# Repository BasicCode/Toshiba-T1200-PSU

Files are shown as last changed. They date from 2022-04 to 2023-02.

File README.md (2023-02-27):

# Toshiba-T1200-PSU
A replacement power supply design for the Toshiba T1200 laptop computer from 1987. The Toshiba T1xxx series are notorious for power supply falures, and the power supply design is complex for the era. While the complicated design did allow for some innovative new power management features for the time, it also allowed for a myriad of annoying failure modes. I say this only because I have not implemented most of the auxiliary features here, but they may be desirable in the future.<br />
<br />
This is revision one, it has the basic requirements to make the machine boot but it lacking any of the extra features of the original supply. **Also, please read the note about input / output protection**. I have used modular power options where possible and have tried to follow the recommended design for the -22V SMPS circuit as closely as possible. Please feel free to improve on this design.
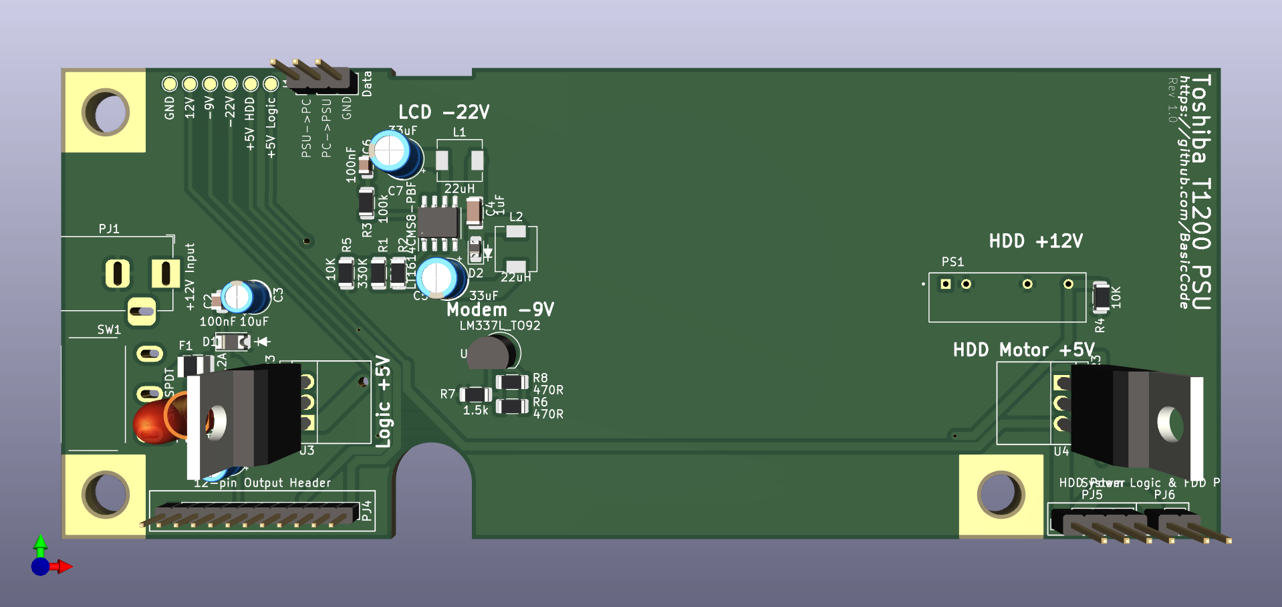
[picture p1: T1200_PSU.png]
Board Simulation


## Getting Started
This board is designed in KiCad 6.x, custom and third-party footprints are included in the repository, and the individual Gerber files are included.
* Parts list for DigiKey is available [here](https://www.digikey.com.au/en/mylists/list/S7I768EYZQ). All of the passives are generic and can be replaced with whatever you have laying around, just take care to use low ESR 33uF caps for the -22V SMPS. Two parts are missing from the list; the female headers for the interconnect between the PSU and the Motherboard. They are generic keyed headers like these: (https://www.jaycar.com.au/4-pin-0-1-header-with-crimp-pins-2-54-pitch/p/HM3404), (https://www.jaycar.com.au/2-pin-0-1-header-with-crimp-pins-2-54-pitch/p/HM3402).
* The board is designed to use 12V, like the original, however the invdividual switchmode supplies have different tollerances so you might be able to get away with other supplies but check the datasheets first.
* I used OSH Park to print the boards (https://oshpark.com/shared_projects/8MR7H5RI).
* The footprint for the DC Barrel Jack 12V input *should* fit the jack on the original PCB if you want to use that, however I have used a more standard size plug and a modern, off-the-shelf, 12V plug pack. The original power supply is rated for 2.2A.
* I measured the whole system at boot to draw approx. 700mA at 12V.
* There is NO output protection, so if you build one of these then make sure to check the voltage rails before using it.

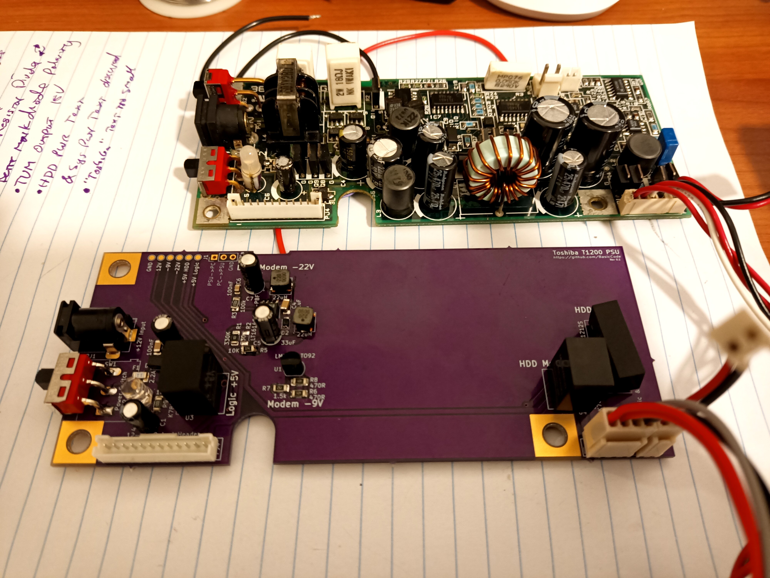
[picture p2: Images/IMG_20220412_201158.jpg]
New board and old board New Board and old board

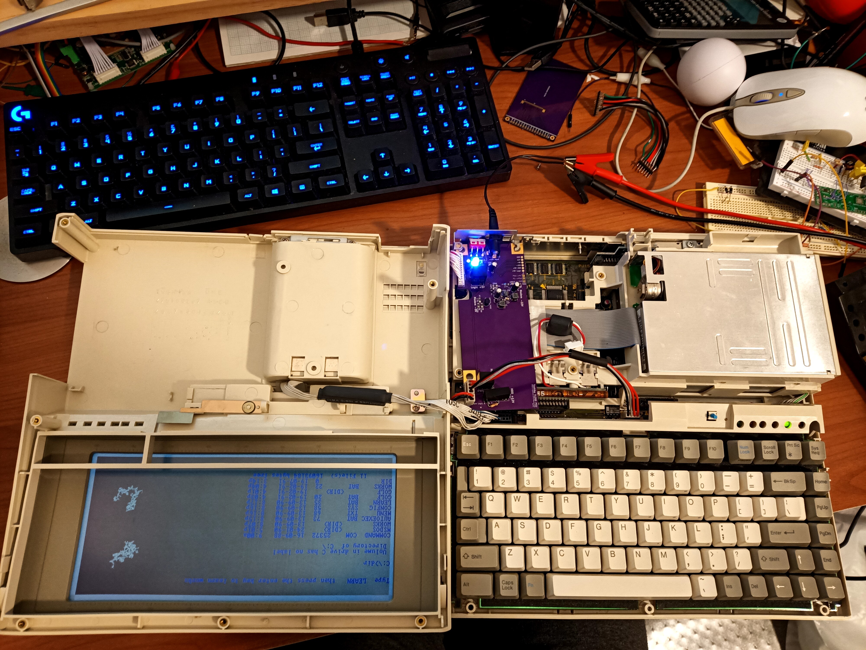
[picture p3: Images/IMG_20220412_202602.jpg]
New board in old computer


## Notes About Input / Output Protection
Basic input protection is included in the design, and there is some protection inherent to the individual SMPS controllers, however there are further considerations that should be made in future designs.
* D1 should be sufficient to supply enough current to blow the 2.2A fuse. The details of D1 are not specified in the schematic.
* Clamping diodes should be added to the outputs. Especially the negative voltage rails which will become positive if D2 fails.
* Over-current protection of the outputs is provided by the individual switchmode controllers.
* Over-voltage protection for the inputs is a consideration, however the individual switchmode supplies affort some protection in this regard.

## TODO
These things would be nice to fix in the next revision.
* Add / Improve output protection
* There is an issue where the HDD power supply block (*PS1*) hits a pastic bump on the case of the laptop. This component should be shifted a few mm to the left in future revisions.

## Future Options
Although I don't plan to implement these features, I've tried to design the circuit with them in mind.
* HDD Power switch.
* Arduino-compatable system to interact with the TX/RX lines.
* LiPo charging, and boost circuit to run off one or two 18650s, OR NiCad.

## Thanks and References
Thanks to these forums for helping sole so many problems:
* https://forum.vcfed.org/index.php?threads/toshiba-t1200-internal-power-supply-issues.72126/
* https://forum.vcfed.org/index.php?threads/toshiba-t1200-psu-pinout.1216344/
* http://www.minuszerodegrees.net/manuals/Toshiba/Other/Toshiba%20T1200%20-%20Maintenance%20Manual.pdf

## Fixed in Rev. 1.0
* Cleaned up custom footprit assets folder.
* DC barrel jack placement.
* TMV1212S open circuit voltage too high. Added load resistor.
* TMV1212S corrected footprint.
* PWR_SW corrected footprint.
* "Toshiba T1200 PSU" text moved.
* Text for PJ5 and PJ6 updated.
* Symbols added to D1, D2.
* C6 and C2 are now the same footprint.

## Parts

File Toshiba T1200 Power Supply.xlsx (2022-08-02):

Index | Manufacturer Part Number | Manufacturer Name | Description | Attrition % | Requested Quantity 1 | Pack Quantity 1 | Pack Type 1 | Digi-Key Part Number 1 | Unit Price 1 | Extended Price 1 | Minimum Order Quantity 1 | Requested Part Number | Datasheet
1 | LM337LZ/NOPB | Texas Instruments | IC REG LIN NEG ADJ 100MA TO92-3 |  | 1 | 1 | Bulk | LM337LZ/NOPB-ND | 1.74000 | $1.74 | 1 | LM337LZ/NOPB-ND | https://www.ti.com/general/docs/suppproductinfo.tsp?distId=10
2 | K7805-2000R3 | Mornsun America, LLC | DC DC CONVERTER 5V 10W |  | 2 | 2 | Tube | 2725-K7805-2000R3-ND | 10.65000 | $21.30 | 1 | 2725-K7805-2000R3-ND | https://www.mornsun-power.com/html/pdf/K7805-2000R3.html
3 | TMV 1212S | Traco Power | DC DC CONVERTER 12V 1W |  | 1 | 1 | Tube | 1951-2509-ND | 8.54000 | $8.54 | 1 | 1951-2509-ND | https://www.tracopower.com/products/tmv.pdf
4 | LT1614CS8#PBF | Analog Devices Inc. | IC REG MULTI CONFG ADJ 8SOIC |  | 1 | 1 | Tube | LT1614CS8#PBF-ND | 10.17000 | $10.17 | 1 | LT1614CS8#PBF-ND | https://www.analog.com/media/en/technical-documentation/data-sheets/1614fs.pdf
5 | VLS5045EX-220M-H | TDK Corporation | FIXED IND 22UH 1.8A 162.5MOHM SM |  | 1 | 1 | Cut Tape (CT) | 445-181623-1-ND | 0.82000 | $0.82 | 1 | 445-181623-1-ND | https://product.tdk.com/system/files/dam/doc/product/inductor/inductor/smd/catalog/inductor_automotive_power_vls5045ex-h_en.pdf
6 | CUHS20F30,H3F | Toshiba Semiconductor and Storage | SCHOTTKY BARRIER DIODE, 30V/2A, |  | 1 | 1 | Cut Tape (CT) | CUHS20F30H3FCT-ND | 0.57000 | $0.57 | 1 | CUHS20F30H3FCT-ND | https://toshiba.semicon-storage.com/info/docget.jsp?did=63604&prodName=CUHS20F30
7 | 1-1735446-2 | TE Connectivity AMP Connectors | CONN HEADER VERT 12POS 2MM |  | 1 | 1 | Bulk | A100106-ND | 0.66000 | $0.66 | 1 | A100106-ND | https://www.te.com/commerce/DocumentDelivery/DDEController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
8 | 0685T2500-01 | Bel Fuse Inc. | FUSE 2.5A 63VAC/DC SLOW 1206 |  | 1 | 1 | Cut Tape (CT) | 507-1895-1-ND | 0.45000 | $0.45 | 1 | 507-1895-1-ND | https://belfuse.com/resources/datasheets/circuitprotection/ds-cp-c1t-series.pdf
9 | 0022112022 | Molex | CONN HEADER VERT 2POS 2.54MM |  | 1 | 1 | Bulk | WM2700-ND | 0.66000 | $0.66 | 1 | WM2700-ND | https://www.molex.com/pdm_docs/sd/022112022_sd.pdf
10 | 0022112042 | Molex | CONN HEADER VERT 4POS 2.54MM |  | 1 | 1 | Bulk | WM2702-ND | 1.11000 | $1.11 | 1 | WM2702-ND | https://www.molex.com/pdm_docs/sd/022112042_sd.pdf
11 | 4840.2201 | SCHURTER Inc. | CONN PWR JACK 2X5.5MM SOLDER |  | 1 | 1 | Bulk | 486-3381-ND | 2.73000 | $2.73 | 1 | 486-3381-ND | https://www.schurterinc.com/bundles/snceschurter/epim/_ProdPool_/newDS/en/typ_4840.2201.pdf
12 | CRG1206F10K | TE Connectivity Passive Product | RES SMD 10K OHM 1% 1/4W 1206 |  | 2 | 2 | Cut Tape (CT) | A106069CT-ND | 0.15000 | $0.30 | 1 | A106069CT-ND | https://www.te.com/commerce/DocumentDelivery/DDEController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
13 | CRG1206F470R | TE Connectivity Passive Product | RES SMD 470 OHM 1% 1/4W 1206 |  | 2 | 2 | Cut Tape (CT) | A106077CT-ND | 0.15000 | $0.30 | 1 | A106077CT-ND | https://www.te.com/commerce/DocumentDelivery/DDEController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
14 | CRGCQ1206F330K | TE Connectivity Passive Product | RES 330K OHM 1% 1/4W 1206 |  | 2 | 2 | Cut Tape (CT) | A129840CT-ND | 0.15000 | $0.30 | 1 | A129840CT-ND | https://www.te.com/commerce/DocumentDelivery/DDEController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
15 | CRGCQ1206F100K | TE Connectivity Passive Product | RES 100K OHM 1% 1/4W 1206 |  | 1 | 1 | Cut Tape (CT) | A129834CT-ND | 0.15000 | $0.15 | 1 | A129834CT-ND | https://www.te.com/commerce/DocumentDelivery/DDEController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
16 | CRGCQ1206F1K5 | TE Connectivity Passive Product | RES 1.5K OHM 1% 1/4W 1206 |  | 1 | 1 | Cut Tape (CT) | A129812CT-ND | 0.15000 | $0.15 | 1 | A129812CT-ND | https://www.te.com/commerce/DocumentDelivery/DDEController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
17 | CRG1206F1K0 | TE Connectivity Passive Product | RES SMD 1K OHM 1% 1/4W 1206 |  | 1 | 1 | Cut Tape (CT) | A106070CT-ND | 0.15000 | $0.15 | 1 | A106070CT-ND | https://www.te.com/commerce/DocumentDelivery/DDEController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
18 | C3216X7R1H105K160AB | TDK Corporation | CAP CER 1UF 50V X7R 1206 |  | 1 | 1 | Cut Tape (CT) | 445-1423-1-ND | 0.39000 | $0.39 | 1 | 445-1423-1-ND | https://product.tdk.com/system/files/dam/doc/product/capacitor/ceramic/mlcc/catalog/mlcc_commercial_general_en.pdf
19 | C2012X8R1H104K125AA | TDK Corporation | CAP CER 0.1UF 50V X8R 0805 |  | 1 | 1 | Cut Tape (CT) | 445-2514-1-ND | 0.27000 | $0.27 | 1 | 445-2514-1-ND | https://product.tdk.com/en/search/set_distributor
20 | ECA-1HHG4R7I | Panasonic Electronic Components | CAP ALUM 4.7UF 20% 50V RADIAL |  | 1 | 1 | Cut Tape (CT) | P19528CT-ND | 0.49000 | $0.49 | 1 | P19528CT-ND | https://industrial.panasonic.com/cdbs/www-data/pdf/RDF0000/ABA0000C1215.pdf
21 | EEU-EB1H100SH | Panasonic Electronic Components | CAP ALUM 10UF 20% 50V RADIAL |  | 1 | 1 | Cut Tape (CT) | P19607CT-ND | 0.63000 | $0.63 | 1 | P19607CT-ND | https://industrial.panasonic.com/cdbs/www-data/pdf/RDF0000/ABA0000C1024.pdf
22 | EEU-HD1H330 | Panasonic Electronic Components | CAP ALUM 33UF 20% 50V RADIAL |  | 2 | 2 | Bulk | P15151-ND | 0.97000 | $1.94 | 1 | P15151-ND | //media.digikey.com/pdf/Data%20Sheets/Panasonic%20Capacitors%20PDFs/EEUHD.pdf
23 | SD1206T040S1R0 | KYOCERA AVX | DIODE SCHOTTKY 40V 1A 1206 |  | 1 | 1 | Cut Tape (CT) | 478-7809-1-ND | 0.66000 | $0.66 | 1 | 478-7809-1-ND | https://datasheets.kyocera-avx.com/schottky.pdf
24 | MT2118-G-A | Marktech Optoelectronics | LED GREEN DIFFUSED 5MM ROUND T/H |  | 1 | 1 | Bulk | 1125-1184-ND | 0.48000 | $0.48 | 1 | 1125-1184-ND | https://marktechopto.com/pdf/products/datasheet/MT2118-G-A.pdf

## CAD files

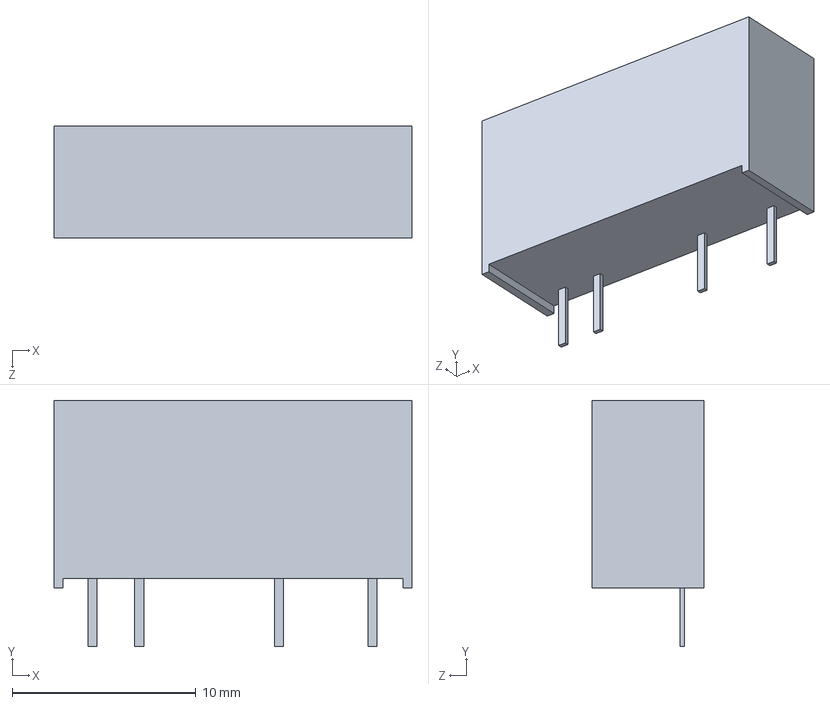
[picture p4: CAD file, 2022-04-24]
custom_assets/TMV_1212S.step
19.5 x 13.4 x 6.10 mm

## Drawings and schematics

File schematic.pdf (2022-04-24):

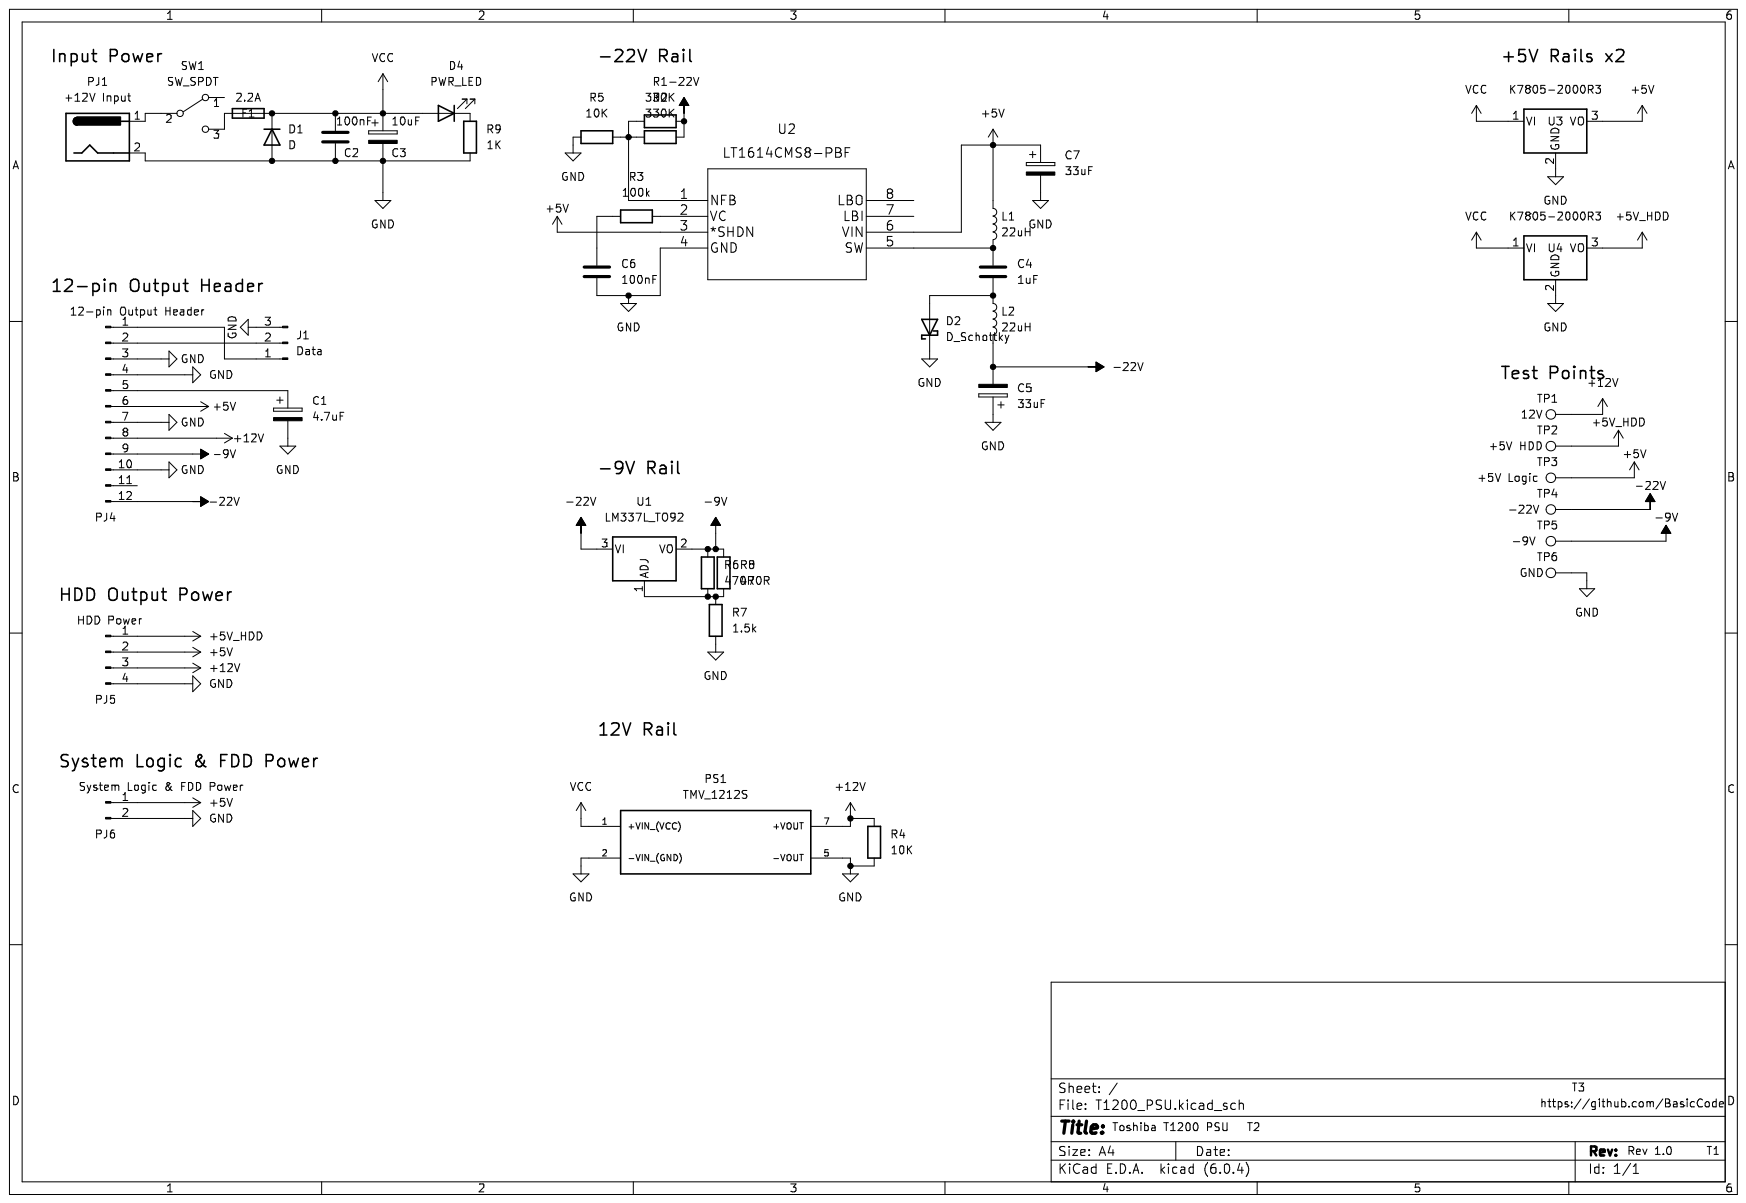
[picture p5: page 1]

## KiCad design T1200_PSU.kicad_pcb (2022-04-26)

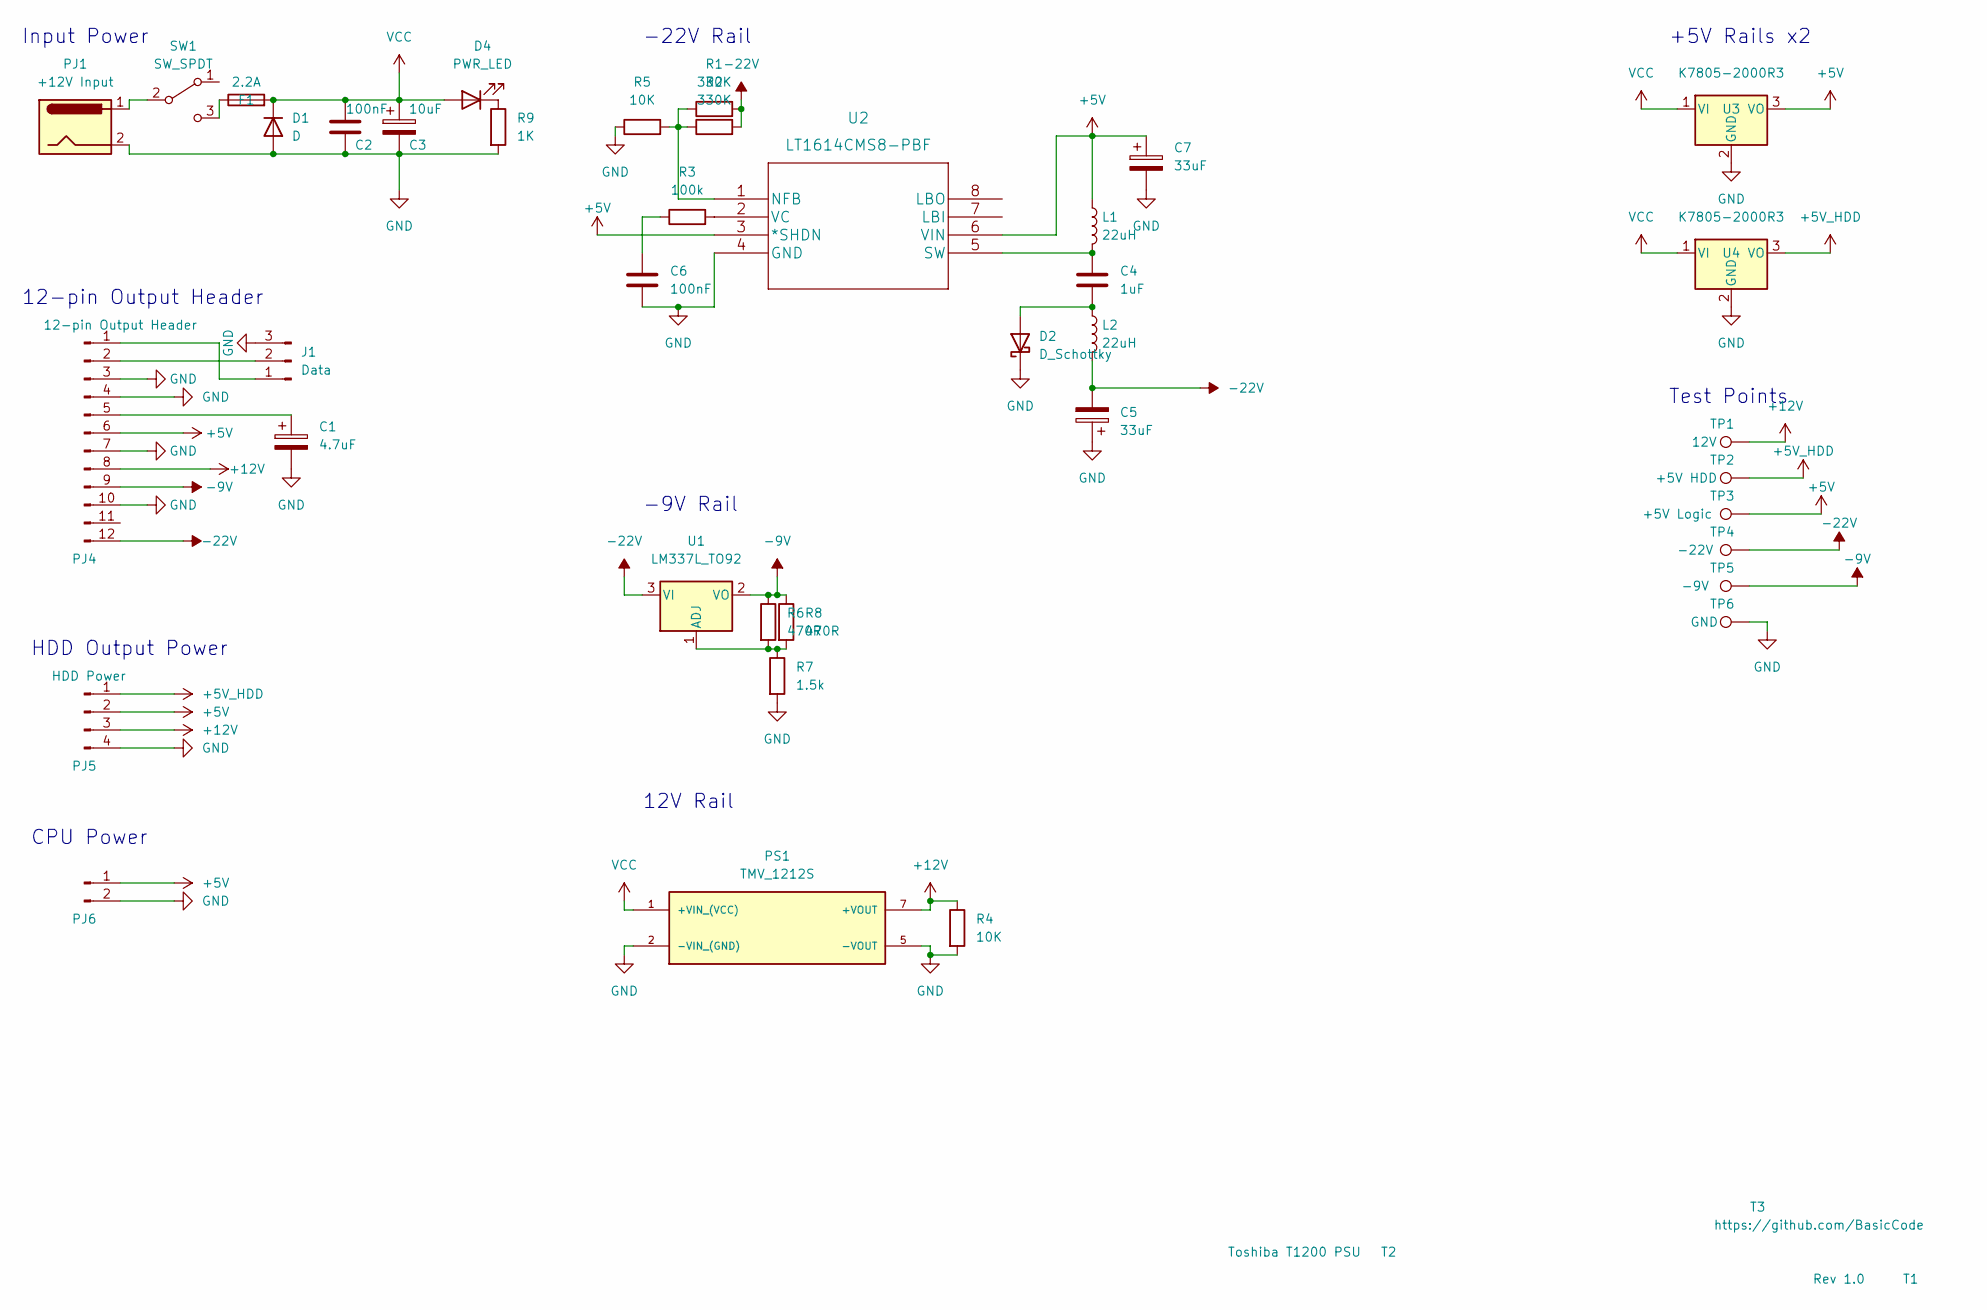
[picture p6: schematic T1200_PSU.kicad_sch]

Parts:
C1: 4.7uF; CP_Radial_D4.0mm_P2.00mm
C2, C6: 100nF; C_0805_2012Metric
C3: 10uF; CP_Radial_D4.0mm_P2.00mm
C4: 1uF; C_1206_3216Metric
C5, C7: 33uF; CP_Radial_D5.0mm_P2.50mm
D1: D; D_1206_3216Metric
D2: D_Schottky; D_0805_2012Metric_Pad1.15x1.40mm_HandSolder
D4: PWR_LED; LED_D5.0mm
F1: 2.2A; Fuse_1210_3225Metric
J1: Data; PinHeader_1x03_P2.54mm_Vertical
L1, L2: 22uH; L_5.3x5.0_H3
PJ1: +12V Input; BarrelJack_Horizontal
PJ4: 12-pin Output Header; PinHeader_1x12_P2.00mm_Vertical
PJ5: HDD Power; PinHeader_1x04_P2.54mm_Vertical
PJ6: PinHeader_1x02_P2.54mm_Vertical
PS1: TMV_1212S; CONV_TMV_1212S; PARTREV March 26, 2020
R1, R2: 330K; R_1206_3216Metric
R3: 100k; R_1206_3216Metric
R4, R5: 10K; R_1206_3216Metric
R6, R8: 470R; R_1206_3216Metric
R7: 1.5k; R_1206_3216Metric
R9: 1K; R_1206_3216Metric
SW1: SW_SPDT; switch
T1: Rev 1.0; text_only
T2: Toshiba T1200 PSU; text_only
T3: https://github.com/BasicCode; text_only
TP1: 12V; TestPoint_Pad_D1.5mm
TP2: +5V HDD; TestPoint_Pad_D1.5mm
TP3: +5V Logic; TestPoint_Pad_D1.5mm
TP4: -22V; TestPoint_Pad_D1.5mm
TP5: -9V; TestPoint_Pad_D1.5mm
TP6: GND; TestPoint_Pad_D1.5mm
U1: LM337L_TO92; TO-92_Inline
U2: LT1614CMS8-PBF; SSOP-8_3.9x5.05mm_P1.27mm
U3, U4: K7805-2000R3; TO-220-3_Vertical

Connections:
+5V: C7.1, L1.1, PJ4.6, PJ5.2, PJ6.1, TP3.1, U2.3 (*SHDN), U2.6 (VIN), U3.3 (VO)
+5V_HDD: PJ5.1, TP2.1, U4.3 (VO)
+12V: PJ4.8, PJ5.3, PS1.7 (+VOUT), R4.1, TP1.1
-9V: PJ4.9, R6.1, R8.1, TP5.1, U1.2 (VO)
-22V: C5.2, L2.2, PJ4.12, R1.2, R2.2, TP4.1, U1.3 (VI)
GND: C1.2, C2.2, C3.2, C5.1, C6.2, C7.2, D1.2 (A), D2.1 (K), J1.3, PJ1.2, PJ4.3, PJ4.4, PJ4.7, PJ4.10, PJ5.4, PJ6.2, PS1.2 (-VIN_(GND)), PS1.5 (-VOUT), R4.2, R5.1, R7.2, R9.2, TP6.1, U2.4 (GND), U3.2 (GND), U4.2 (GND)
unnamed: C1.1, PJ4.5
unnamed: C4.1, L1.2, U2.5 (SW)
unnamed: C4.2, D2.2 (A), L2.1
unnamed: C6.1, R3.1
unnamed: D4.1 (K), R9.1
unnamed: F1.1, SW1.3 (C)
unnamed: J1.1, PJ4.1
unnamed: J1.2, PJ4.2
unnamed: PJ1.1, SW1.2 (B)
unnamed: R1.1, R2.1, R5.2, U2.1 (NFB)
unnamed: R3.2, U2.2 (VC)
unnamed: R6.2, R7.1, R8.2, U1.1 (ADJ)
VCC: C2.1, C3.1, D1.1 (K), D4.2 (A), F1.2, PS1.1 (+VIN_(VCC)), U3.1 (VI), U4.1 (VI)

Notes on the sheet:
+5V Rails x2
-22V Rail
Test Points
HDD Output Power
CPU Power
Input Power
12-pin Output Header
12V Rail
-9V Rail

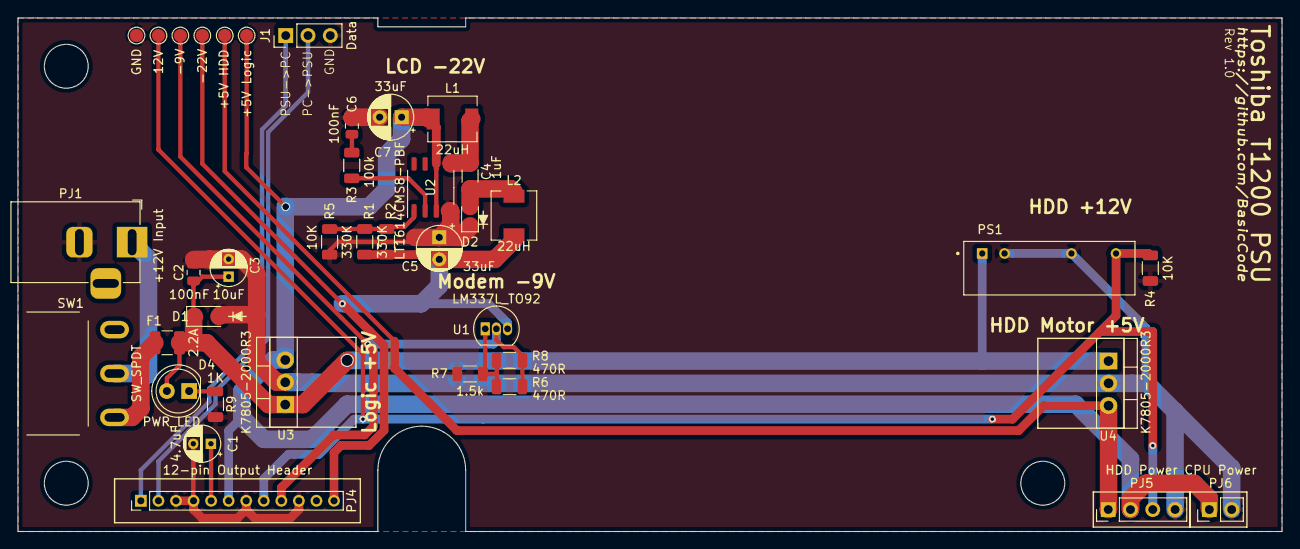
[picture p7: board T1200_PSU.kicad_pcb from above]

Board: 2 copper layers, 144.0 x 58.5 mm, 42 parts (0 on the bottom side), 19 nets.

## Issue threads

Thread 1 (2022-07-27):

Part List

gadjodilo83, 2022-07-27:
Hi!

A great project!
Is there a simple parts list of the components?

You may be able to provide us with a confirmation (e.g. Digikey) of your order for the components.
I have already ordered the PCB, thank you for your efforts!

Thanks
Marc

BasicCode, 2022-08-02:
Hi,
Glad you're finding it useful. Sorry for the delay with the parts list. Most of it came from Digikey but a few parts were just general items I had laying around in boxes so I had to try and find them on Digikey. I have made a list which contains MOST of the parts needed.
https://github.com/BasicCode/Toshiba-T1200-PSU/blob/3f3613d4c2f3fc39c498c8727aeb8e1fbedf5eb0/Toshiba%20T1200%20Power%20Supply.xlsx

A couple of parts are missing because I couldn't find them:

- The connectors for the cables linking the power supply to the main board. I found the headers but not the female cable sockets. I got mine from Jaycar:
https://www.jaycar.com.au/4-pin-0-1-header-with-crimp-pins-2-54-pitch/p/HM3404
https://www.jaycar.com.au/2-pin-0-1-header-with-crimp-pins-2-54-pitch/p/HM3402

- I used generic resistors and ceramic caps, however the 33uF electrolytic should be low ESR caps from a reputable brand.
- Use an LED colour of your choice. :)

gadjodilo83, 2022-08-10:
Hi,

Thanks you so much for your big work!
The list is a great help to me! I have ordered the components and hope the laptop can be used again :)

I have already received the circuit board! Looks very good!

Thanks again

Marc

BasicCode, 2022-08-17:
Great to hear it's helpful. Good luck with the build. Let me know if you have any trouble and I'll try to help.

Closed 2022-08-02.

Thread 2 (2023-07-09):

D1 and D2 values not listed

trs-eric, 2023-07-09:
D1 and D2 are not labeled on the schematic as to their recommended values. Not sure which diode goes where.

BasicCode, 2023-07-27:
I intend to do an update soon with some output protection and better input protection.
In the meantime; the values for D1 and D2 don't matter too much. They both need to be Schottky type diodes with a reverse voltage of at least 30V. D1 needs to be able to handle at least 2A current (see note under Input / Output Protection).

trs-eric, 2023-07-27:
Sounds great, thanks! Another issue I noticed, and I'm not sure if this requires a new issue, but I built five of these and all 5 had an issue with the fuse not flowing properly. I think the fuse footprint may be wrong. Otherwise they worked great and brought two machines back to life :) Thanks!

BasicCode, 2023-07-28:
Thanks for the feedback! I'm glad to hear the project is helping. :) I discovered a fault with mine where fuse blew after being left unused for an extended period. Hopefully it was just inrush current and can be fixed with a fusable resistor but I'll do some investigation, then a board revision.

trs-eric, 2023-07-28:
oh good deal, let us know if you come up with a bodge for the current revision

BasicCode, 2024-04-10:
Fixed in commit https://github.com/BasicCode/Toshiba-T1200-PSU/commit/82d8209bb4b3c766f32ac45ca0579c6cf8cf03bb

Closed 2024-04-10.

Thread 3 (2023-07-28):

Fuse Blows After Being Unused For An Extended Period

BasicCode, 2023-07-28:
Fuse F1 has blown after the device was left unused for an extended period. Hopefully it is just inrush current and needs a fusable resistor.

BasicCode, 2023-07-29:
This was not actually a problem with the fuse. The actual problem was that I have bored out the center hole of the barrel-jack on the power supply from repeated use during testing and now it does not make contact properly. I had erroneously measured the fuse to be open but it was in fact fine.

Closed 2023-07-29.

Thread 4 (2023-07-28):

HDD Power Supply Too Close To Case

BasicCode, 2023-07-28:
HDD Power Supply PS1 sits very close to the outer plastic case and hits up against the injection point for the plastic mould.

BasicCode, 2024-04-10:
Fixed in commit https://github.com/BasicCode/Toshiba-T1200-PSU/commit/82d8209bb4b3c766f32ac45ca0579c6cf8cf03bb

Closed 2024-04-10.

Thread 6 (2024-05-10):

Test Points Are Too Close Together

BasicCode, 2024-05-10:
Test point pins (TP1, 2, 3, 4, 5, and 6) are close together and easy to bridge with a multimeter probe if you have had too much coffee. Bridging some of these pins, especially the +12V rail, can cause catastrophic damage. These should be spaced further apart in a future revision.

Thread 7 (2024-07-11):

Add a choke to the -22V rail

BasicCode, 2024-07-11:
There is a lot of noise coming through the -22V rail, OR the 5V rail, and out to the DC input which could be bad for the power supply.

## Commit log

2022-04-24 revision 1.0
    [T1200_PSU-B_Cu.gbr, T1200_PSU-B_Mask.gbr, T1200_PSU-B_Paste.gbr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]
2022-04-26 update documentation
    [T1200_PSU.kicad_pcb, T1200_PSU.kicad_sch]
2022-05-07 clean up old files
    [T1200_PSU.csv]
2022-08-02 added BOM file for DigiKey
    [Toshiba T1200 Power Supply.xlsx]
